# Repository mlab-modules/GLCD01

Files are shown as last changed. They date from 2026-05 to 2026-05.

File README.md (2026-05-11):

# GLCD01 - MIP LCD display module

MLAB module for the [TN0181ANVNANN-GN00](doc/datasheets/MIP_LCD.pdf) square MIP (Memory-in-Pixel) LCD display. MIP displays retain the image without power, making them suitable for low-power applications. The display is connected via a 10-pin FPC connector (J2) and communicates over a 3-wire SPI interface (SCLK, SI, SCS).

The module includes a [MIC1557](https://www.microchip.com/en-us/product/mic1557) RC oscillator that generates the required VCOM polarity-reversal signal for the LCD, so no external signal source is needed. Power supply is 3.3 V via the standard MLAB 2×7 pin header (J1).

## Design

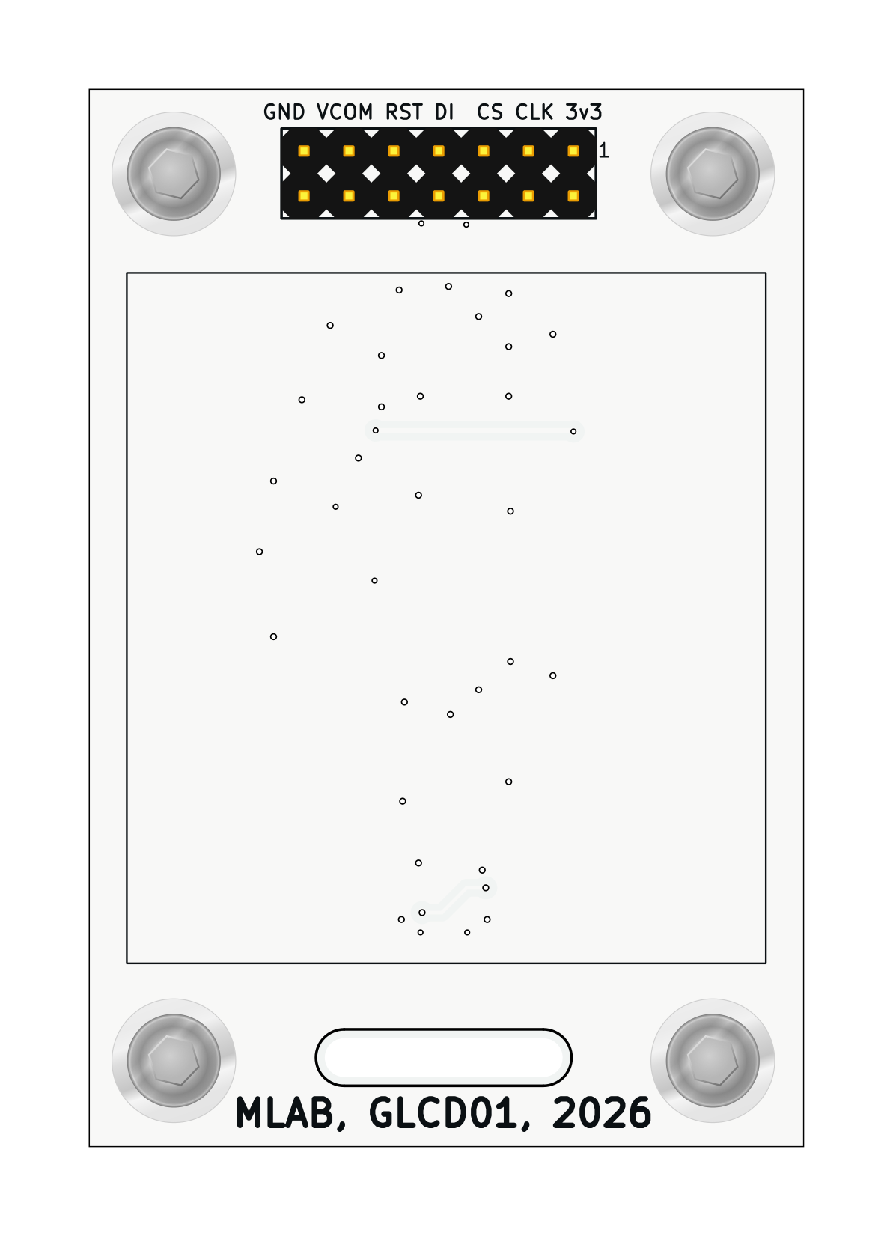
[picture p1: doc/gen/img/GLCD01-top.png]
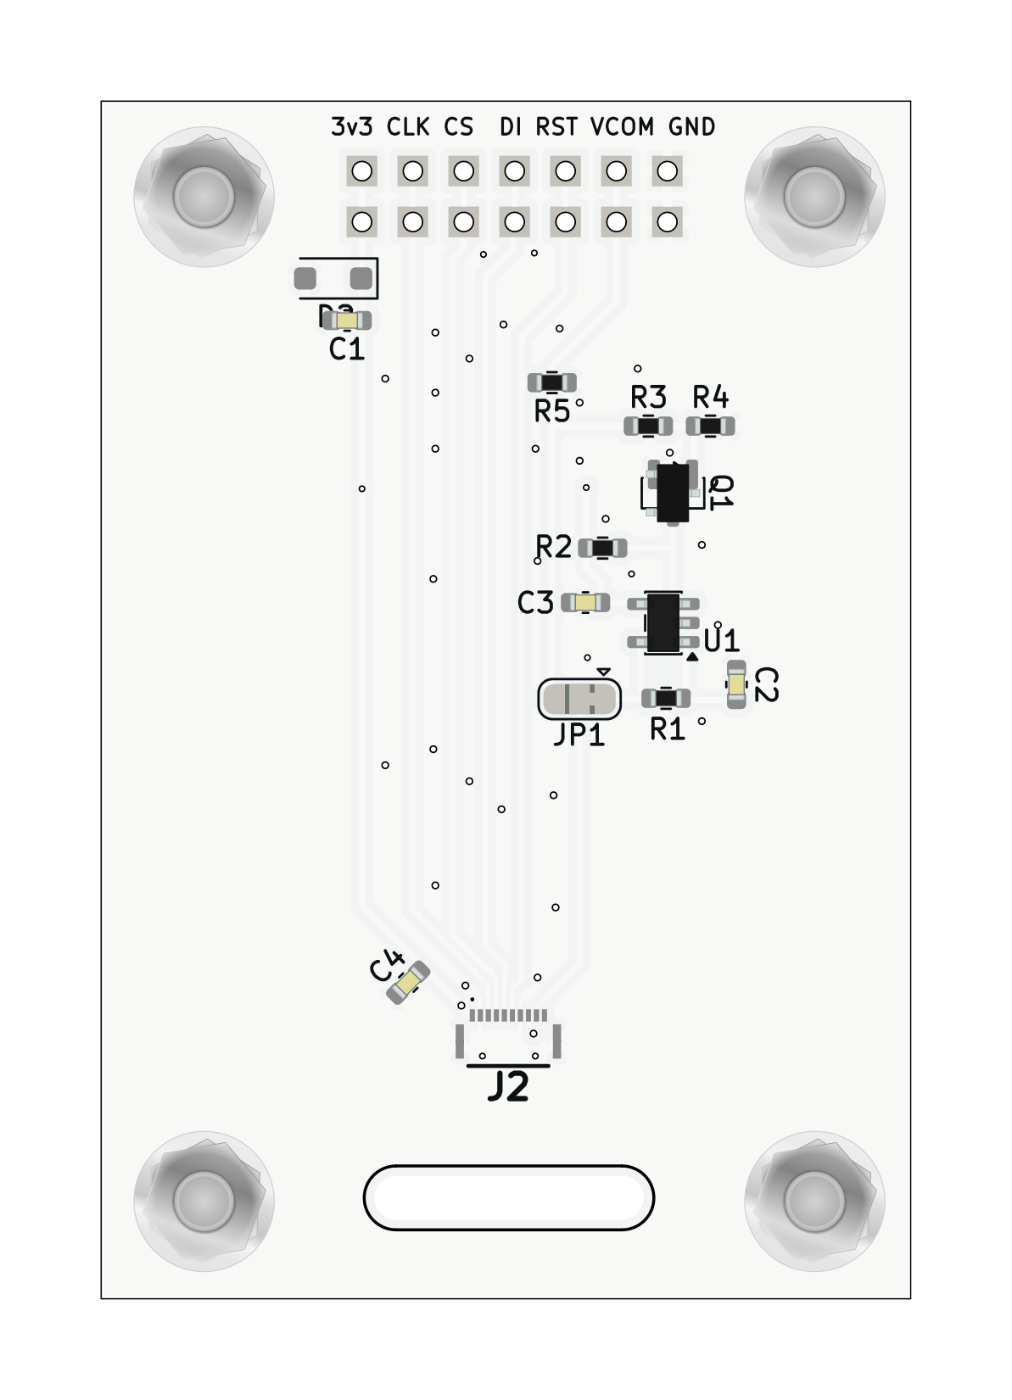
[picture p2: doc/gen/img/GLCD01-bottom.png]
 

## Schematics

Schematics

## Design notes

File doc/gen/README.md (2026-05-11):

# PCB

Board size: 40.49x59.88 mm (1.59x2.36 inches)

- This is the size of the rectangle that contains the board
- Thickness: 1.6 mm (63 mils)
- Material: FR4
- Finish: None
- Layers: 2
- Copper thickness: 35 µm

Solder mask: TOP / BOTTOM

- Color: Green

Silk screen: TOP / BOTTOM

- Color: White

Stackup:

| Name | Type | Color | Thickness [µm]| Material | Er | Loss tan |
|---|---|---|---|---|---|---|
| F.SilkS | Top Silk Screen | | | | | |
| F.Paste | Top Solder Paste | | | | | |
| F.Mask | Top Solder Mask | | 10 | | | |
| F.Cu | copper | | 35 | | | |
| dielectric 1 | core | | 1510 | FR4 | 4.5 | 0.020 |
| B.Cu | copper | | 35 | | | |
| B.Mask | Bottom Solder Mask | | 10 | | | |
| B.Paste | Bottom Solder Paste  | | | | | |
| B.SilkS | Bottom Silk Screen | | | | | |

# Important sizes

Clearance: 0.15 mm (6 mils)

Track width: 0.2 mm (8 mils)

- By design rules: 0.15 mm (6 mils)

Drill: 0.3 mm (12 mils)

- Vias: 0.3 mm (12 mils) [Design: 0.3 mm (12 mils)]
- Pads: 1.0 mm (39 mils)
- The above values are real drill sizes, they add 0.1 mm (4 mils) to plated holes (PTH)

Via: 0.46/0.2 mm (18/8 mils)

- By design rules: 0.4/0.2 mm (16/8 mils)
- Micro via: yes [0.15/0.1 mm (6/4 mils)]
- Buried/blind via: yes
- Total: 39 (thru: 39 buried/blind: 0 micro: 0)

Outer Annular Ring: 0.08 mm (3 mils)

- By design rules: 0.08 mm (3 mils)

Eurocircuits class: 6E
- Using min drill 0.2 mm for an OAR of 0.13 mm

# General stats

Components count: (SMD/THT)

- Top: 0/5 (THT)
- Bottom: 13/0 (SMD)

Defined tracks:

- 0.2 mm (8 mils)
- 0.3 mm (12 mils)

Used tracks:

- 0.2 mm (8 mils) (24) defined: yes
- 0.3 mm (12 mils) (62) defined: yes

Defined vias:

- 0.5/0.25 mm (20/10 mils)

Used vias:

- 0.46/0.2 mm (18/8 mils) (Count: 8, Aspect: 3.5 A) defined: no
- 0.5/0.25 mm (20/10 mils) (Count: 31, Aspect: 3.2 A) defined: yes

Holes (excluding vias):

- 0.89 mm (35 mils) (14)
- 3.0 mm (118 mils) (4)

Oval holes:

Drill tools (including vias and computing adjusts and rounding):

- 0.3 mm (12 mils) (8)
- 0.35 mm (14 mils) (31)
- 1.0 mm (39 mils) (14)
- 3.1 mm (122 mils) (4)

Solder paste stats:

Using a paste with 87.75 % alloy, that has an specific gravity for the alloy of 7.4 g/cm³
and 1.0 g/cm³ for the flux. This paste has an specific gravity of  4.15 g/cm³.

The stencil thickness is  0.12 mm.

| Side | Pads with paste | Area [mm²] | Paste [g] |
|---|---|---|---|
| Total  | 40 | 25.31 | 0.13 |

Note: this is just an approximation to the theoretical value. Margins of the solder mask and waste aren't computed.

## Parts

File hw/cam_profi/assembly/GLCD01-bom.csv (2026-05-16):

Component | Description | Part | References | Value | Footprint | Quantity Per PCB | Datasheet | ust_id | height | mouser part number | mouser price/stock | manufacturer_name | manufacturer_part_number
1 | Unpolarized capacitor, small symbol | C_Small | C3C4 | 100n | C_0603_1608Metric | 2
2 | Unpolarized capacitor, small symbol | C_Small | C1 | 10u | C_0603_1608Metric | 1
3 | GRM21BR71H105KA12L - nutno dodrzet typ | C_Small | C2 | GRM21BR71H105KA12L | C_0603_1608Metric | 1
4 | Zener diode | D_Zener | D2 | BZT52H-C3V6,115 | D_SOD-123F | 1 |  | 650b35ab462c6d9e720543d0
5 | 10 Position FPC Connector Contacts, Top and Bottom 0.016" (0.40mm) Surface Mount, Right Angle | 046824610000846+ | J2 | 046824610000846+ | 046824610000846 | 1 | https://ele.kyocera.com/assets/products/connector/6824.pdf |  | 1 | 346-046824610000846 | https://www.mouser.co.uk/ProductDetail/KYOCERA-AVX/046824610000846%2b?qs=d0WKAl%252BL4KbtJKCl38078A%3D%3D | Kyocera AVX | 046824610000846+
6 | MLAB modified doubled pinheader connector | JUMP_7X2 | J1 | JUMP_7X2 | Straight_2x07 | 1
7 | 50V Vds, 0.22A Id, N-Channel MOSFET, SOT-23 | BSS138 | Q1 | BSS138 | SOT-23 | 1 | https://www.onsemi.com/pub/Collateral/BSS138-D.PDF
8 | Resistor, small symbol | R_Small | R3 | 1k | R_0603_1608Metric | 1
9 | Resistor, small symbol | R_Small | R5 | 10k | R_0603_1608Metric | 1
10 | Resistor, small symbol | R_Small | R1 | 750k | R_0603_1608Metric | 1
11 | Resistor, small symbol | R_Small | R2R4 | 1M | R_0603_1608Metric | 2
12 |  | MIC1557YM5-TR | U1 | MIC1557YM5-TR | SOT-23-5 | 1 | MIC1557YM5-TR

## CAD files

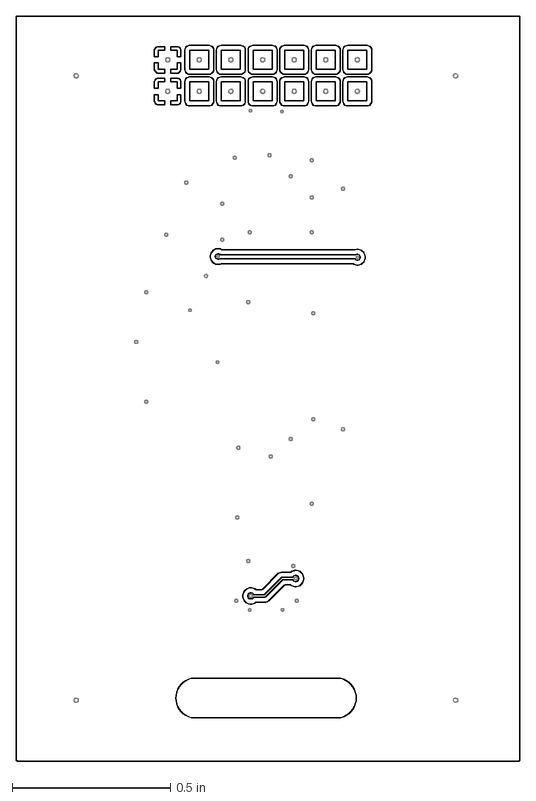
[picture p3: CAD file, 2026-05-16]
doc/gen/dxf/GLCD01-F_Cu.dxf
1.59 x 2.36 in

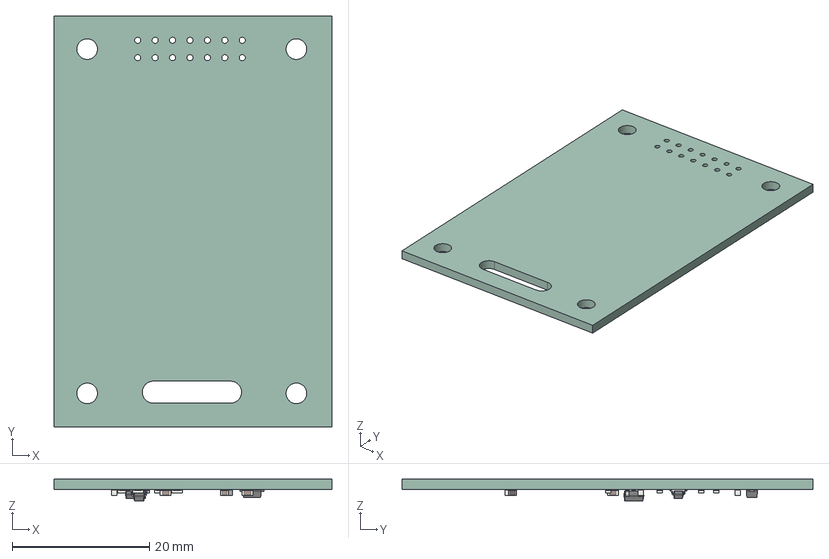
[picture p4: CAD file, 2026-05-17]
doc/gen/GLCD01.step
40.5 x 59.9 x 3.15 mm
R_0603_1608Metric x 5
C_0603_1608Metric x 4
D_SOD-123F
SOT-23-5
SOT-23
kibot_3299_6mr_PCB

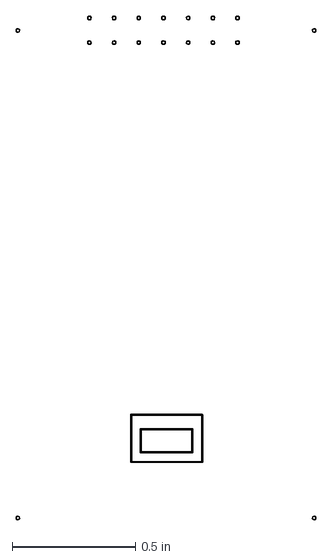
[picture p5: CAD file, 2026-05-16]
doc/gen/dxf/GLCD01-User_Drawings.dxf
1.21 x 2.04 in

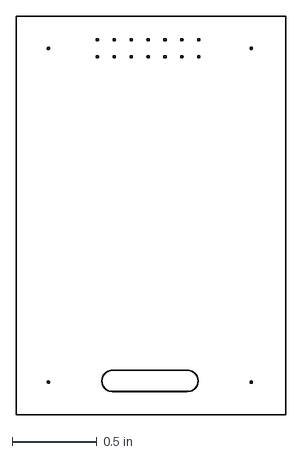
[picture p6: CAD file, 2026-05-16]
doc/gen/dxf/GLCD01-Edge_Cuts.dxf
1.59 x 2.36 in

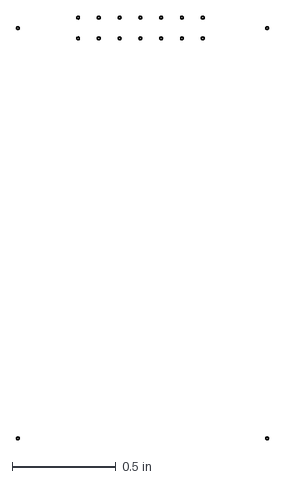
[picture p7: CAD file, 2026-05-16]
doc/gen/dxf/GLCD01-User_2.dxf
1.21 x 2.04 in

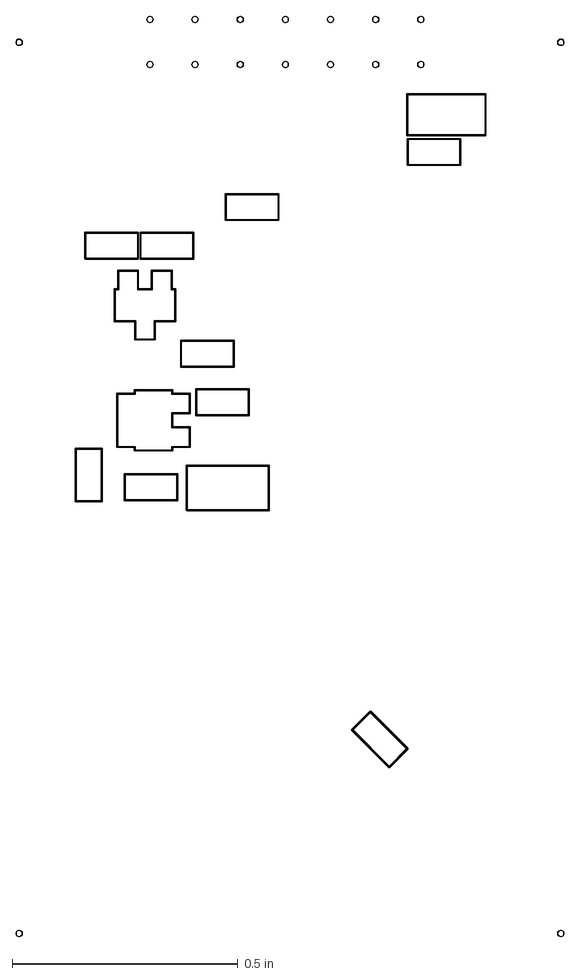
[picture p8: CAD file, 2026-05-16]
doc/gen/dxf/GLCD01-B_Courtyard.dxf
1.21 x 2.04 in

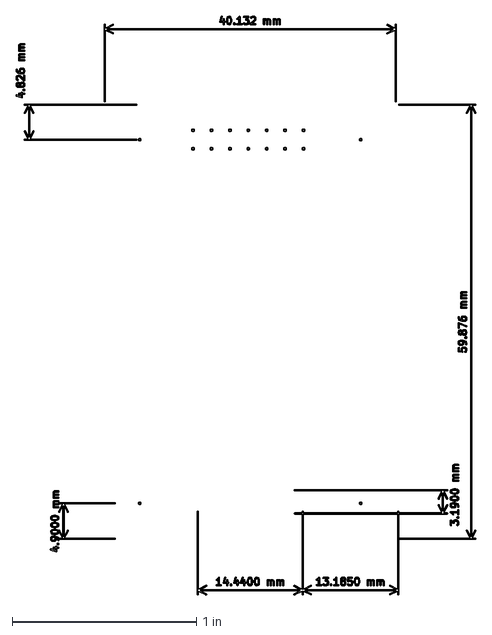
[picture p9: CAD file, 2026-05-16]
doc/gen/dxf/GLCD01-User_Comments.dxf
2.50 x 3.14 in

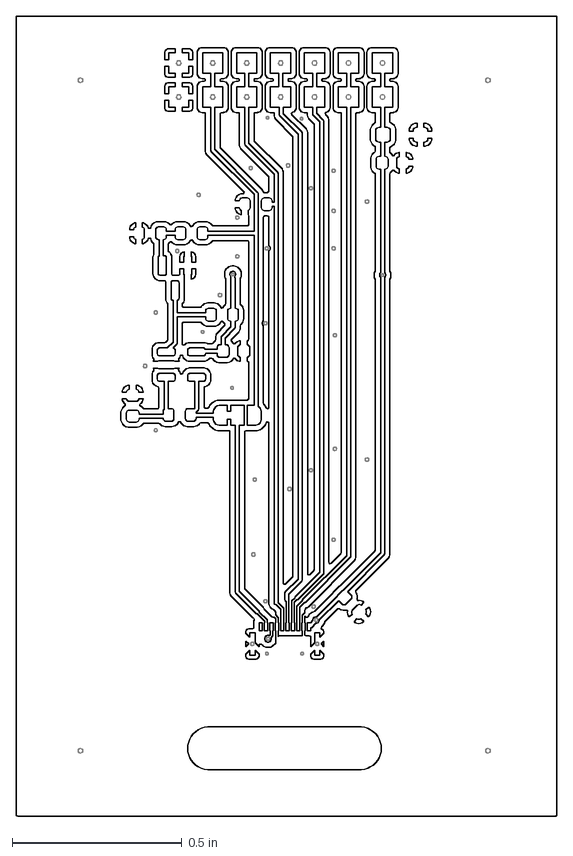
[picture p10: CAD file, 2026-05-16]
doc/gen/dxf/GLCD01-B_Cu.dxf
1.59 x 2.36 in

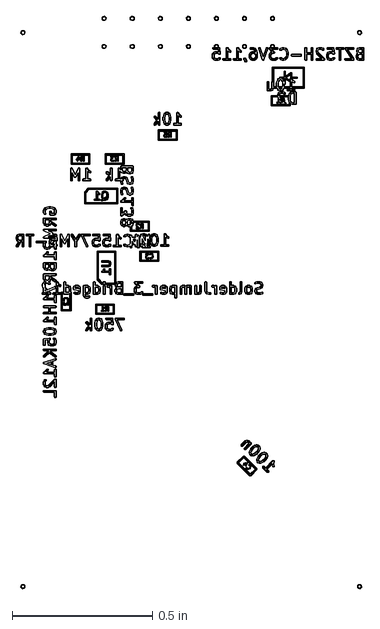
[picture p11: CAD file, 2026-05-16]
doc/gen/dxf/GLCD01-B_Fab.dxf
1.24 x 2.04 in

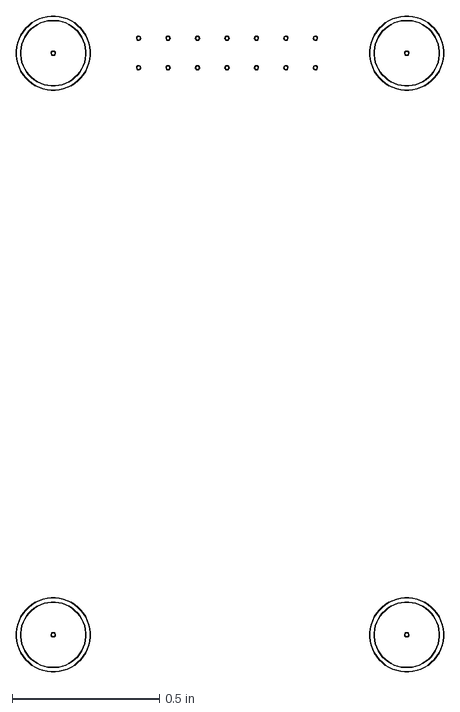
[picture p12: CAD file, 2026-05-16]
doc/gen/dxf/GLCD01-F_Fab.dxf
1.45 x 2.23 in

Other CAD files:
doc/gen/dxf/GLCD01-B_Adhesive.dxf
doc/gen/dxf/GLCD01-B_Mask.dxf
doc/gen/dxf/GLCD01-B_Paste.dxf
doc/gen/dxf/GLCD01-B_Silkscreen.dxf
doc/gen/dxf/GLCD01-F_Adhesive.dxf
doc/gen/dxf/GLCD01-F_Mask.dxf
doc/gen/dxf/GLCD01-F_Paste.dxf
doc/gen/dxf/GLCD01-F_Silkscreen.dxf

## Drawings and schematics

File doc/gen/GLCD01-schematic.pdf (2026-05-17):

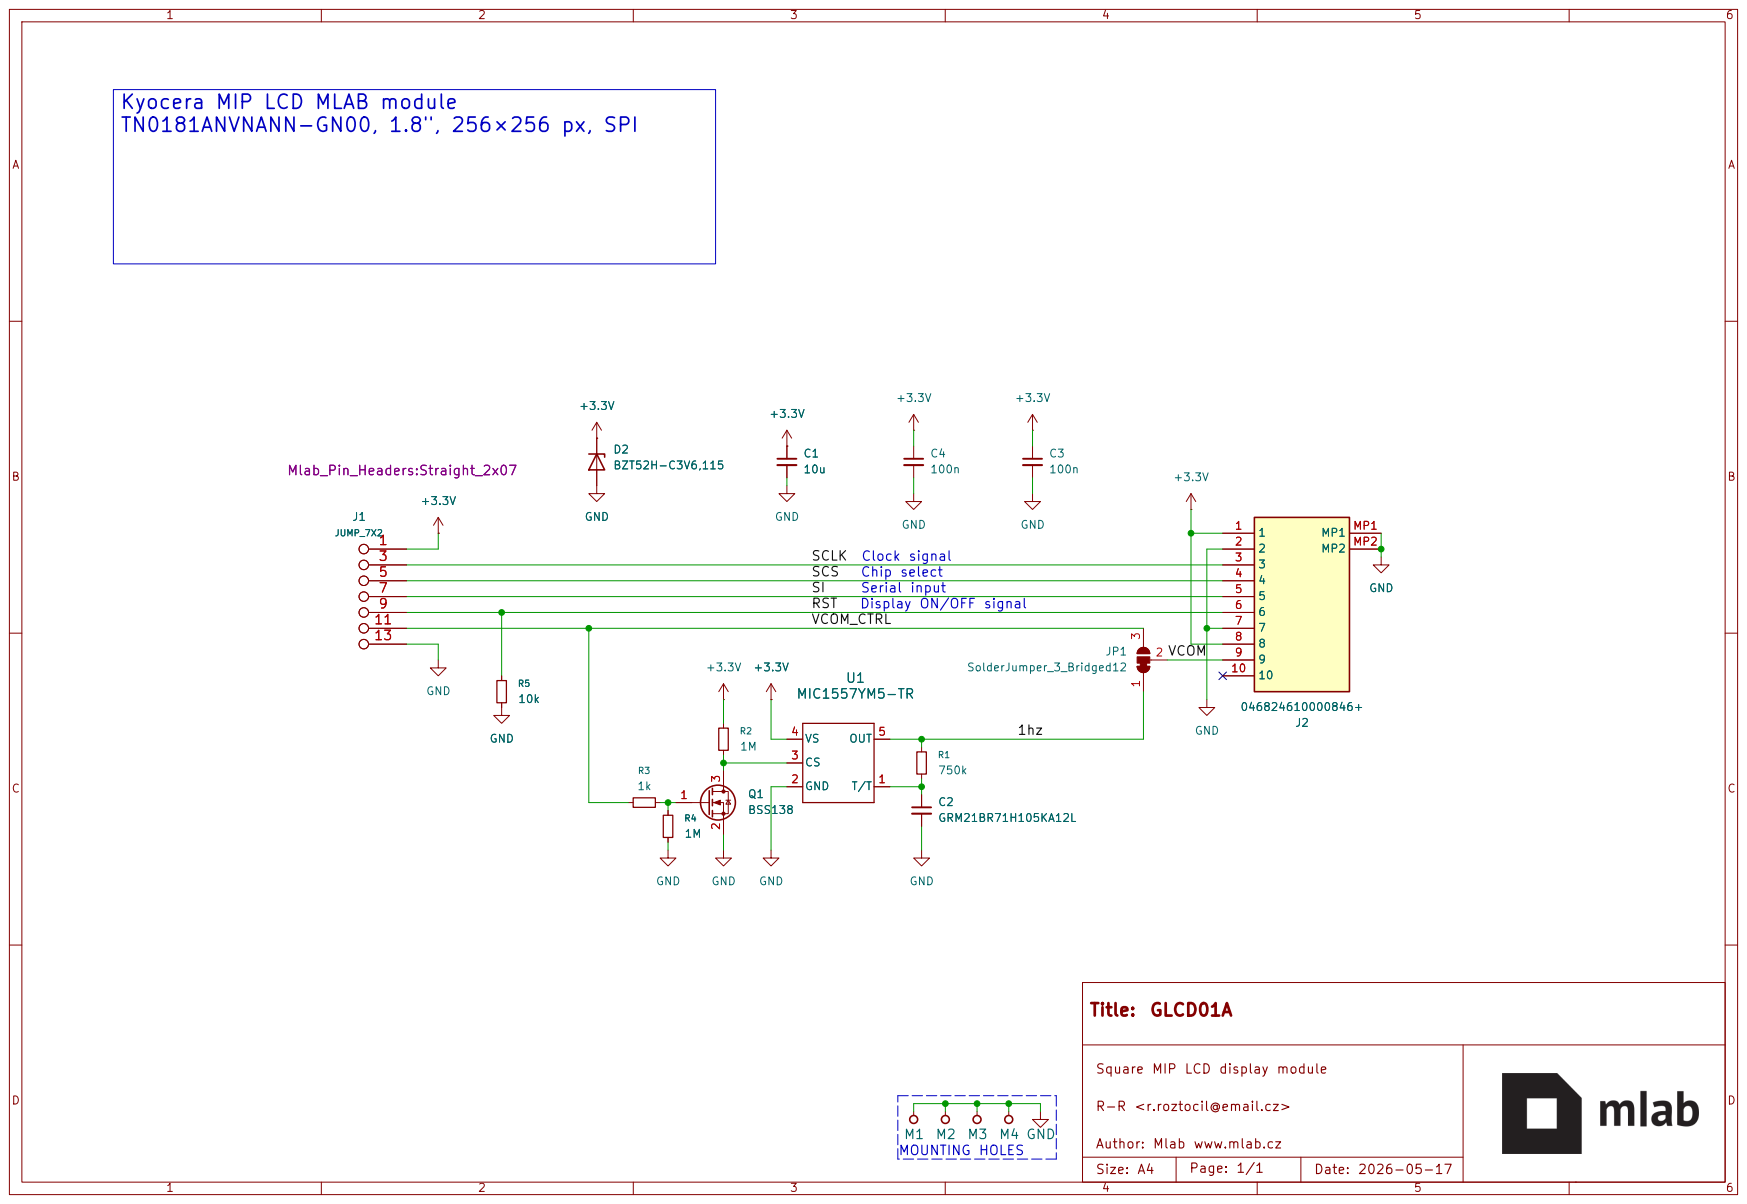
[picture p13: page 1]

Kyocera MIP LCD MLAB module
TN0181ANVNANN-GN00, 1.8", 256×256 px, SPI

Serial input
Display ON/OFF signal

Square MIP LCD display module R-R <r.roztocil@email.cz> Author: Mlab www.mlab.cz

Size: A4 | Page: 1/1 | Date: 2026-05-17

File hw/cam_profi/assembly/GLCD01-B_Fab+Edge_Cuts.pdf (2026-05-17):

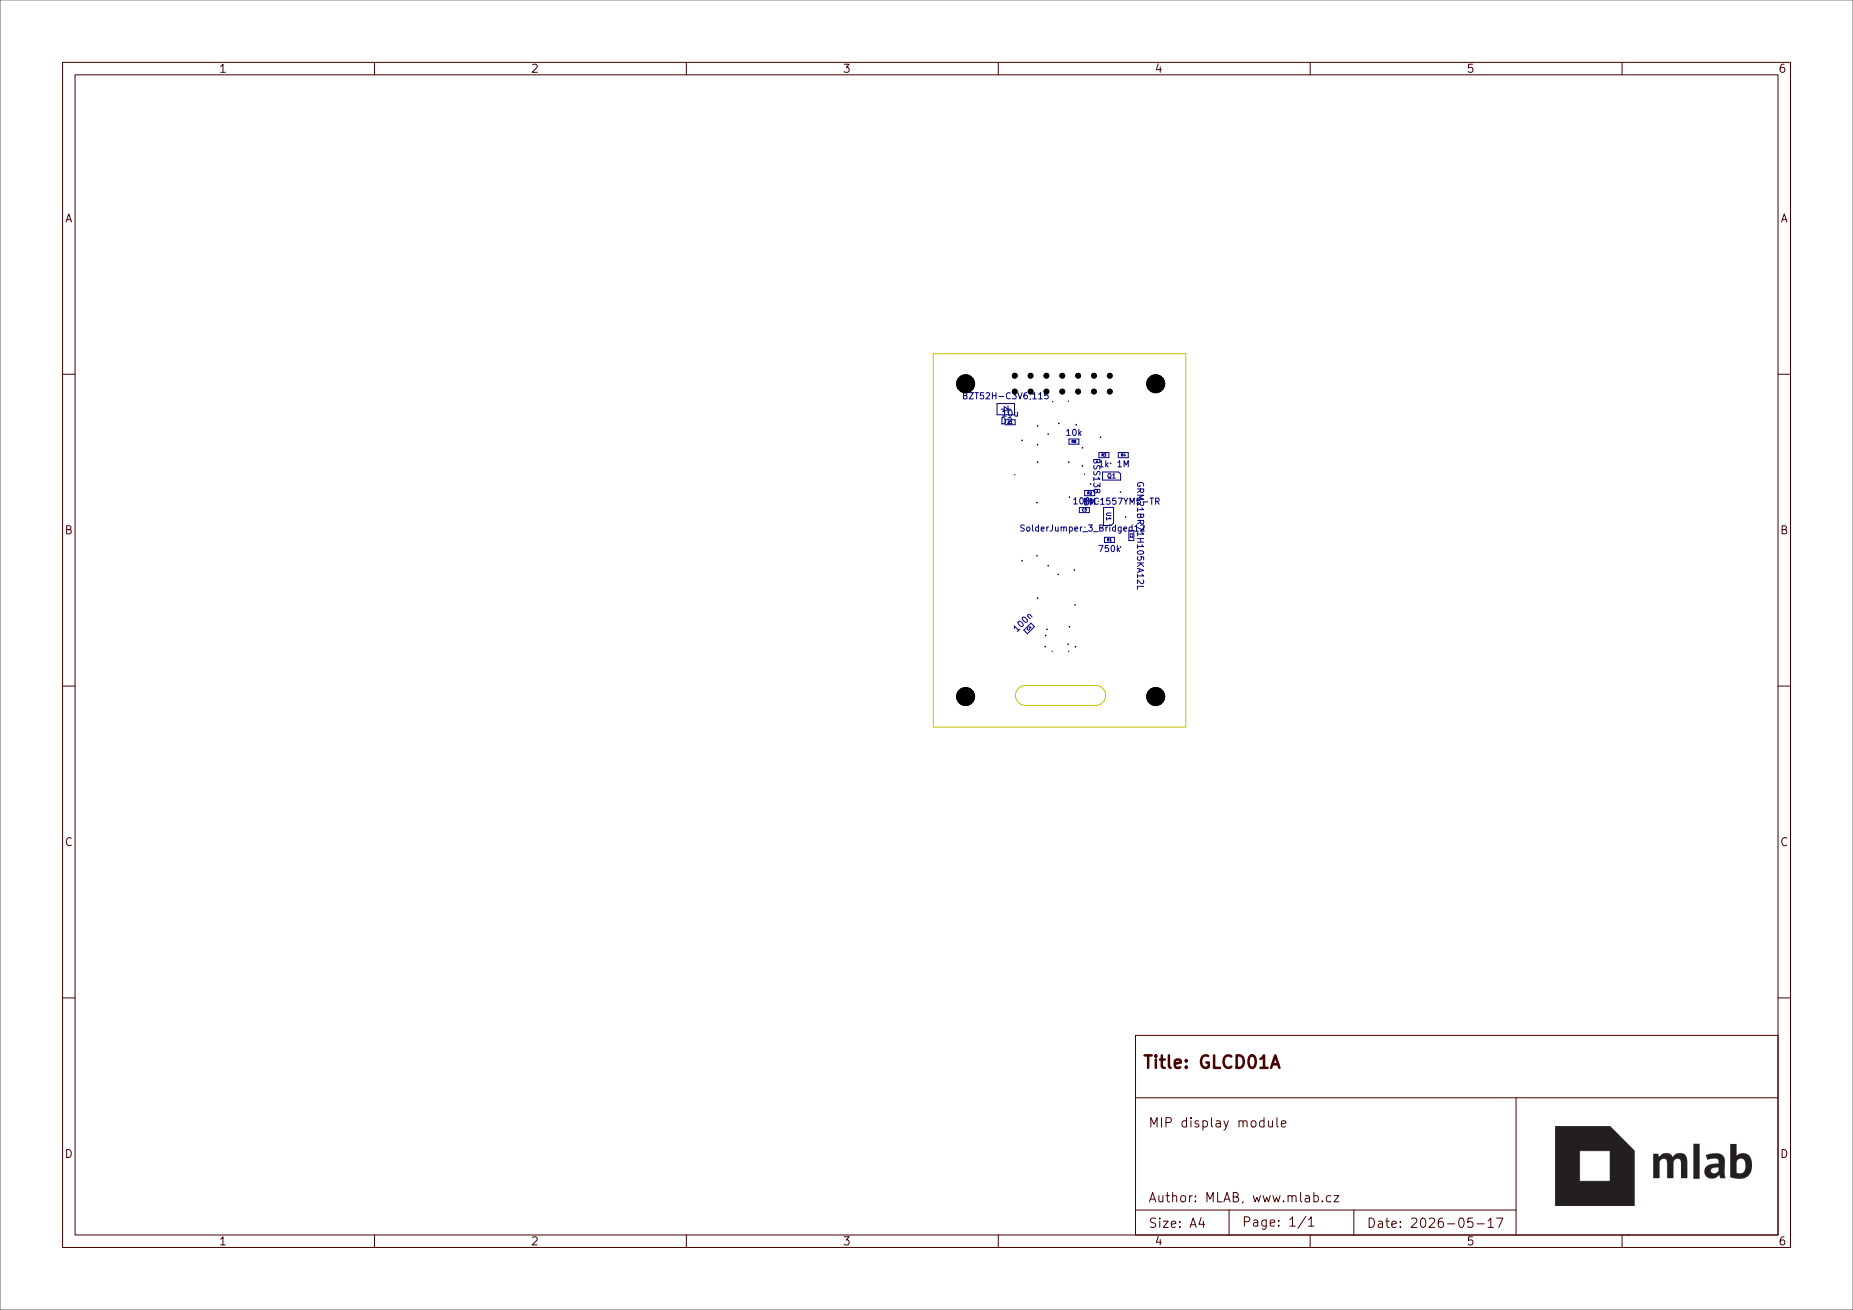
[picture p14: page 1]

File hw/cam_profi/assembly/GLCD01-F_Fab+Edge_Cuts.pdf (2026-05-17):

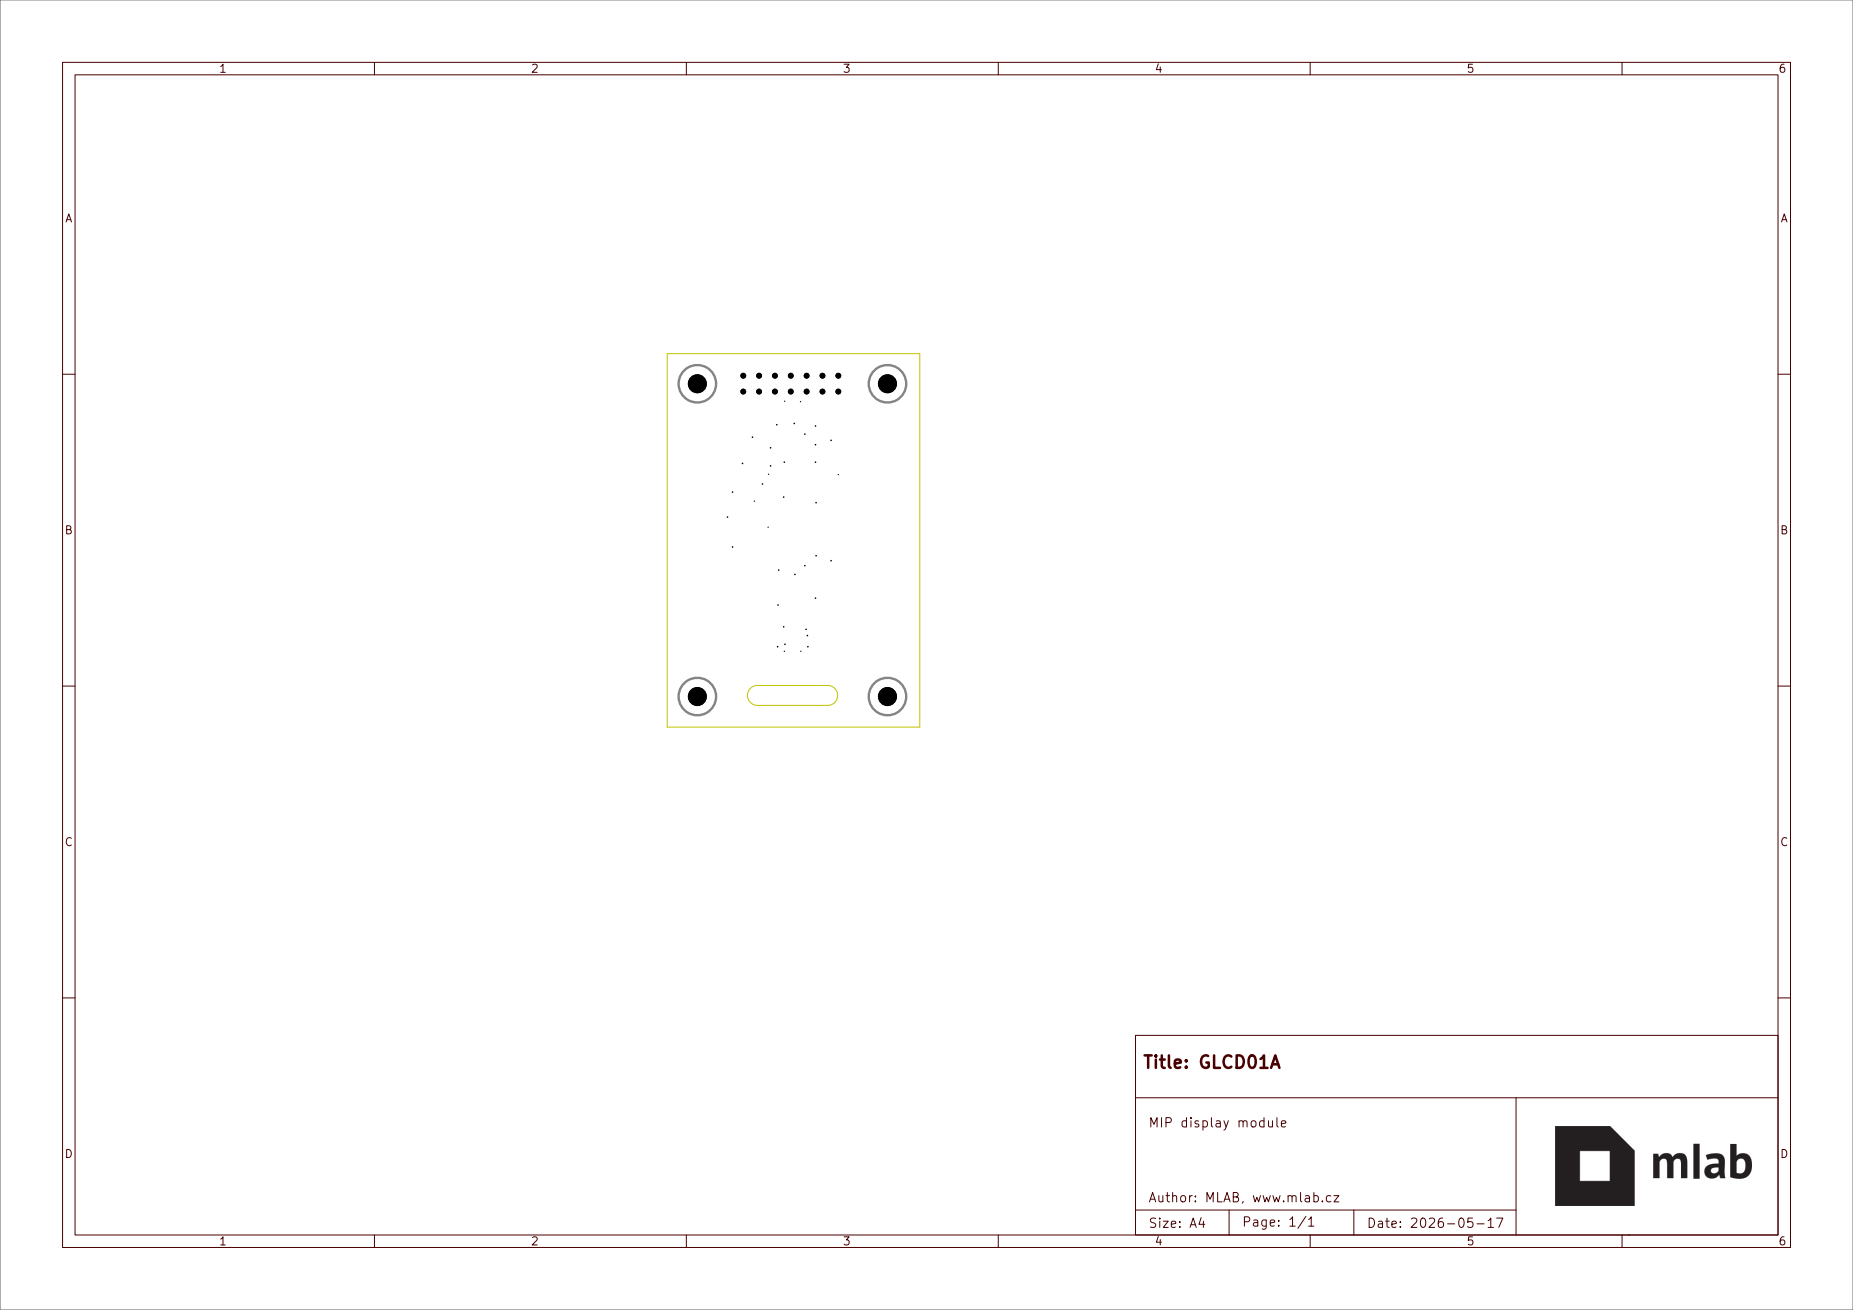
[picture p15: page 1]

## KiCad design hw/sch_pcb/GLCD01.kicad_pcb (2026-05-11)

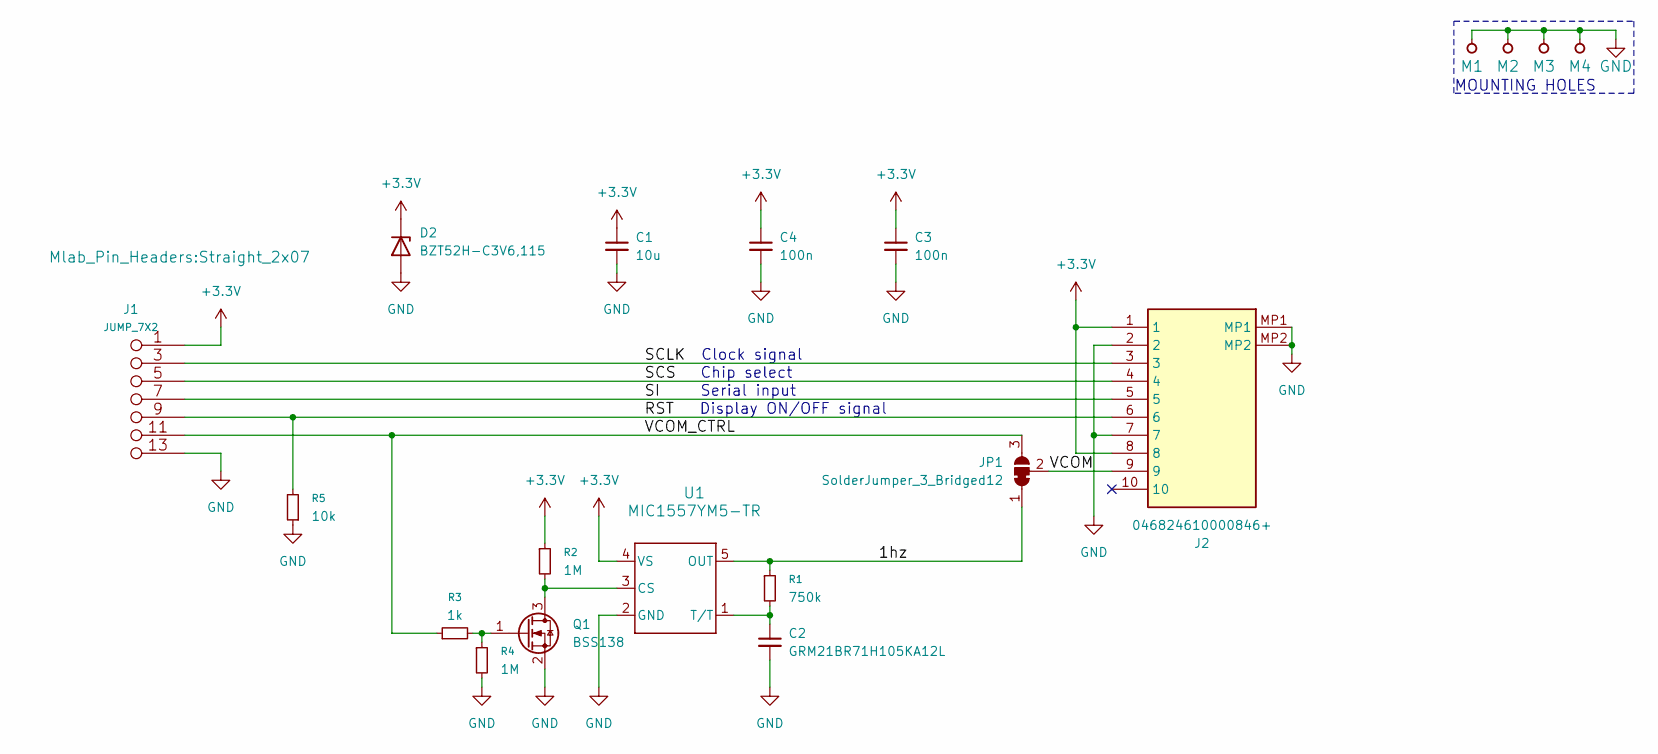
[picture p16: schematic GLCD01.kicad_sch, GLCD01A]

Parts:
C1: 10u; C_0603_1608Metric
C2: GRM21BR71H105KA12L; C_0603_1608Metric
C3, C4: 100n; C_0603_1608Metric
D2: BZT52H-C3V6,115; D_SOD-123F
J1: JUMP_7X2; Straight_2x07
J2: 046824610000846+; 046824610000846; Mouser Part Number 346-046824610000846
JP1: SolderJumper_3_Bridged12; SolderJumper-3_P1.3mm_Bridged12_RoundedPad1.0x1.5mm
M1, M2: HOLE M3; MountingHole_3mm
M3, M4: HOLE; MountingHole_3mm
Q1: BSS138; SOT-23
R1: 750k; R_0603_1608Metric
R2, R4: 1M; R_0603_1608Metric
R3: 1k; R_0603_1608Metric
R5: 10k; R_0603_1608Metric
U1: MIC1557YM5-TR; SOT-23-5

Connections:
+3.3V: C1.1, C3.1, C4.1, D2.1 (K), J1.1 (2), J1.2, J2.1, J2.8, R2.1, U1.4 (VS)
/1hz: JP1.1 (A), R1.1, U1.5 (OUT)
/RST: J1.9 (10), J1.10, J2.6, R5.2
/SCLK: J1.3 (4), J1.4, J2.3
/SCS: J1.5 (6), J1.6, J2.4
/SI: J1.7 (8), J1.8, J2.5
/VCOM: J2.9, JP1.2 (C)
/VCOM_CTRL: J1.11 (12), J1.12, JP1.3 (B), R3.1
GND: C1.2, C2.2, C3.2, C4.2, D2.2 (A), J1.13 (14), J1.14, J2.2, J2.7, J2.MP1, J2.MP2, M1.1, M2.1, M3.1, M4.1, Q1.2 (S), R4.2, R5.1, U1.2 (GND)
unnamed: Q1.3 (D), R2.2, U1.3 (CS)
unnamed: Q1.1 (G), R3.2, R4.1
unnamed: C2.1, R1.2, U1.1 (T/T)

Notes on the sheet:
Display ON/OFF signal
Clock signal
MOUNTING HOLES
Serial input
Chip select

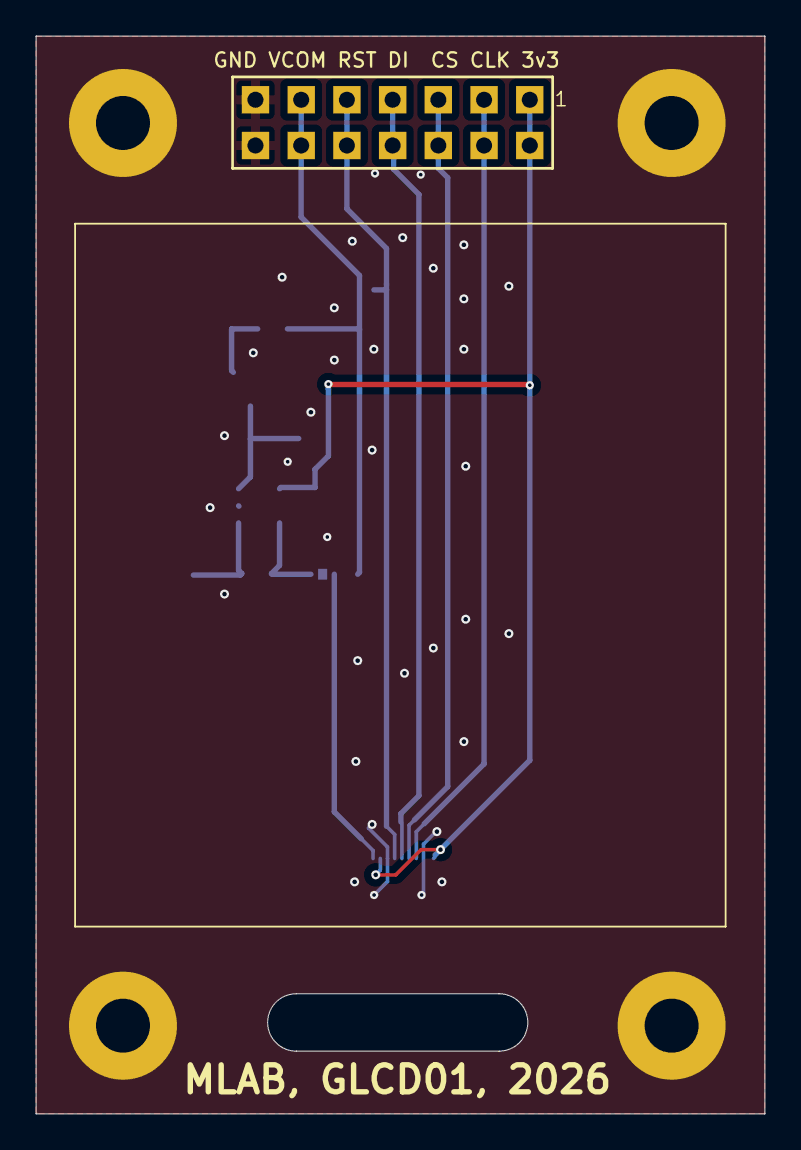
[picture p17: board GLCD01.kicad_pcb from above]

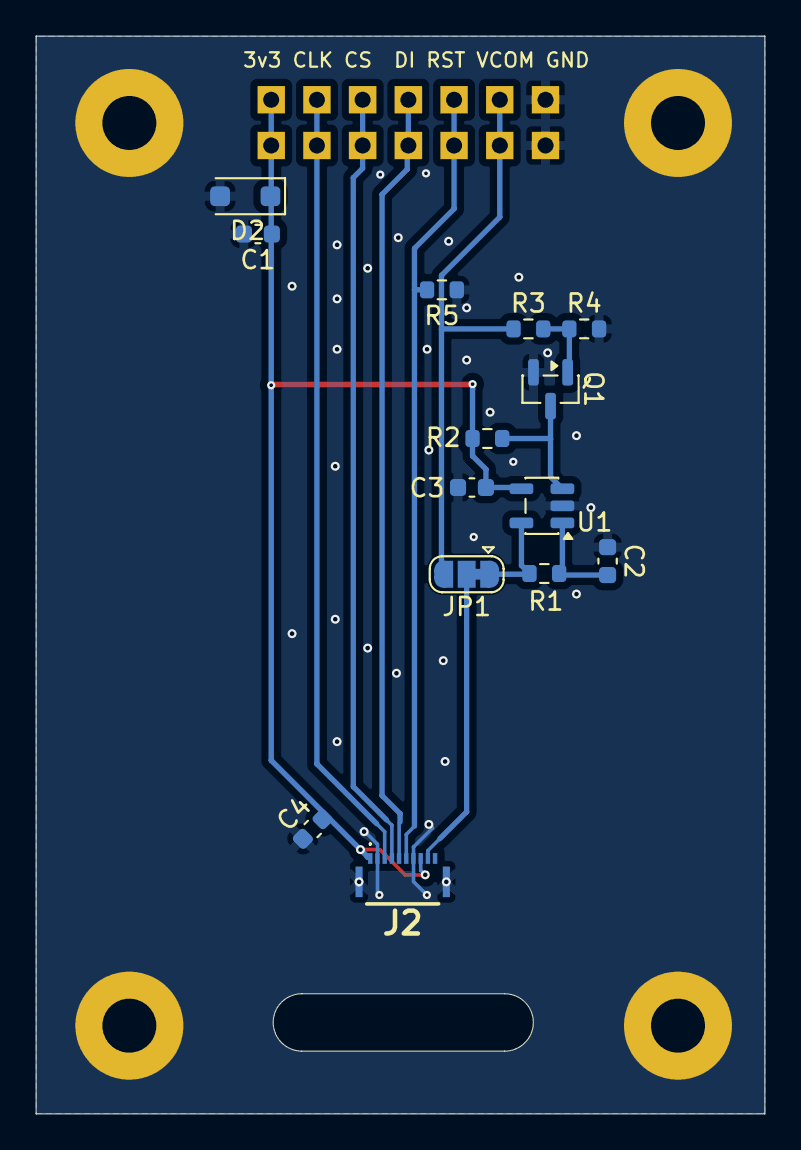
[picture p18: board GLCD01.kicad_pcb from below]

Board: 2 copper layers, 40.5 x 59.9 mm, 19 parts (14 on the bottom side), 12 nets.

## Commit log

2026-02-28 Initial KiCAD project template commit.
    [GLCD01.kicad_pcb, GLCD01.kicad_sch]
2026-02-28 Automatic update of KiCAD outputs
    [GLCD01-B_Adhesive.dxf, GLCD01-B_Courtyard.dxf, GLCD01-B_Cu.dxf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]
2026-03-18 v1 with mic1557
    [GLCD01.kicad_pcb, GLCD01.kicad_sch]
2026-05-06 Add MIC1557 circuit to schematic and update PCB layout
    - Added R5 (0R, DNP) resistor to schematic
    - Rearranged component placement on PCB
    - Updated project file to newer KiCAD format
    - Fixed author email in schematic title block
    [GLCD01.kicad_pcb, GLCD01.kicad_sch]
2026-05-06 Update PCB layout and tighten DRC rules
    Reduced clearance and hole constraints for denser routing.
    [GLCD01.kicad_pcb]
2026-05-11 fix schematics, improve layout, thicker traces, update layout, add polarity protection, ...
    [GLCD01.kicad_pcb, GLCD01.kicad_sch]
2026-05-11 readme, text to schematics
    [GLCD01.kicad_sch]
